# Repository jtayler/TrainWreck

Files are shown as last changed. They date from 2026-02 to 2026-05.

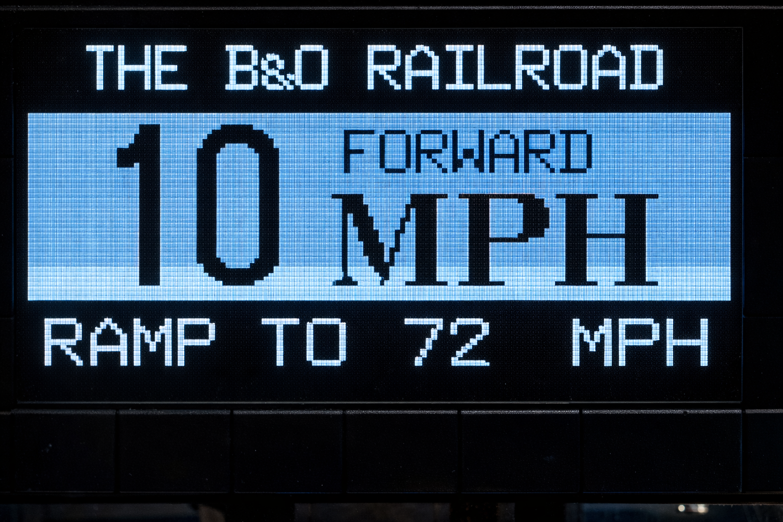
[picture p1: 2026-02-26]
controltower.com/images/display.png

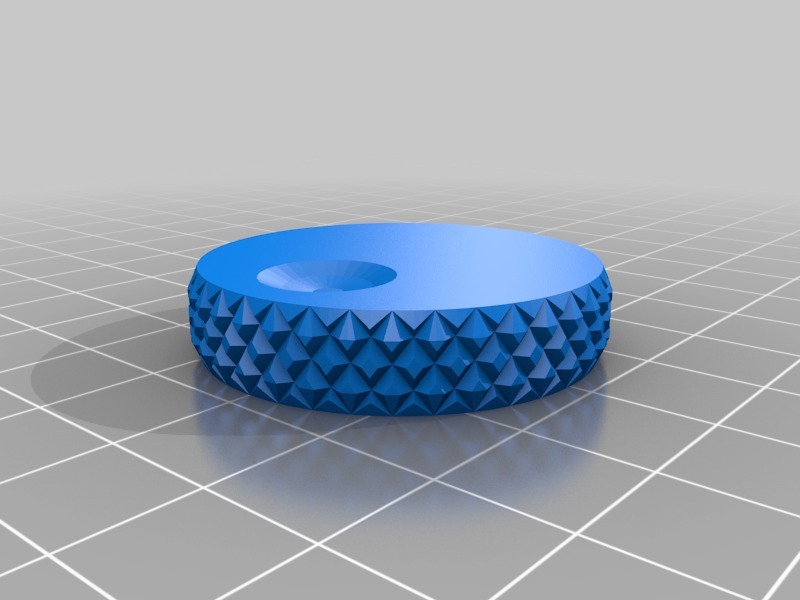
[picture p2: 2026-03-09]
case/Knob/knurled_LCD-knob-2-dent.jpg

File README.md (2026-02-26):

# RailStation — Control Tower  
### Powered by RailOS™

> **A luxury smart power controller for any model train.**  
> RailStation replaces a “dumb” power supply with our special **control tower**. A smart control tower is a power controller with an integrated full-size traffic light; smooth motion, a large digital display, automatic station docking, and synchronized signal and lighting choreography.
> **Easy to enjoy.** Grab the knob anytime for manual override—let go and it glides back into automation. The large display changes with a click to show the list of Routes and you can scroll and pipck another Route, or click and hold a long-press to adjust settings and save them.

---

## What it does (in one minute)

- **Auto-calibrates to your layout** so station finding literally “just works.”
- Runs **scripted routes** with realistic pacing, raping speed and a human feel.
- Drives a **real traffic light** (top-and-center) + **station lights** with choreography.
- Supports **Z to G scale** by respecting a configurable power ceiling.
- The built-in series of fun Lines will run for **2–3 hours continuously** and will repeat in an endless loop.

---

## Signature features

### Smooth motion you can feel
RailOS uses non-linear ramping so starts/stops feel intentional—no lurch, no toy throttle vibe.

### Large, luxurious display
A large, elegant display turns your train into the centerpiece — with a beautifully simple interface that makes control effortless.

### Station docking that actually lands
A TINY IR sensor is used for automatic station arrival behavior: approach → crawl → stop → dwell → depart.

### Real signals, not decoration
**Traffic Light**
- **🔴 Red**: Halted / at-station
- **🟡 Yellow**: Decelerating / slow leg
- **🟢 Green**: Accelerating / fast leg

### Station lights with choreography
Four “posts” are programmable as a group:
- arrival blink patterns
- alternating pairs
- departure urgency
- slow fade-out to dark

Plus one extra output for “anything”: gate motor, windmill, sign, beacon, etc.

### Manual override that feels natural
Turn the knob → you’re in control instantly.  
Release it → after a brief pause, RailOS blends you back into the active route smoothly.

---

## Route Library (examples)
A RailStation isn’t just speed—it’s **story**. Each route has a personality:
- Pennsylvania Line
- California Zephyr
- The Orient Express
- Reading Railroad
- Flying Scotsman
- Hudson River Ltd
- 20th Century Ltd
- Taking Pelham 123  
…and more.

Routes are **editable, reorderable, deletable** and your changes **stick**.

---

## The “Human Element” controls (simple, but deep)

RailOS keeps it easy: you pick a line, and a few “human” traits shape the feel.

### Schedule (when are we running?)
- **HIGH_FREQ** — subway-like: short waits, quick turnarounds, more movement  
- **PEAK** — purposeful: brisk legs, tighter dwell times, fewer “lingers”  
- **OFF_PEAK** — relaxed: longer dwells, calmer pacing, more breathing room  

### Equipment (what kind of train is this?)
- **BULLET** — confident acceleration, longer fast legs, shorter crawls  
- **SHUTTLE** — frequent stops, shorter legs, snappy station work  
- **FREIGHT** — heavier feel: longer ramps, longer slow legs, deliberate departures  

### Service (how predictable is it?)
- **NONSTOP** — fewer station events, more continuous running  
- **LIMITED** — selective stops, “express” pacing and timing  
- **UNPREDICTABLE** — controlled variation: small changes that feel human, not random  

### Range (what kind of run is this?)
- **LOCAL** — close stations, frequent choreography, short dwell cycles  
- **SHORT_RUN** — medium legs, balanced station time  
- **LONG_HAUL** — longer cruising legs, fewer but more “cinematic” station moments  

These traits automatically influence:
- station dwell time
- leg length and speed targets
- ramp aggressiveness
- lighting choreography timing
- controlled variation (the “human element”)

---

## Scales & power
RailStation works across scales by capping output with **MAX_SPEED**:
- tiny trains (T/Z) behave safely
- large trains (O/G) still feel powerful
- same controller, different ceiling

---

## RailOS 1.0
RailOS is the C++ firmware that runs RailStation Control Tower:
- motion physics + ramp engine
- station sensor logic
- profile persistence (edits stick)
- signal + station light choreography
- continuous route runner
- manual override blending

---

## Our Motto
**Easy to enjoy.**  
**Your train. Our brain.**

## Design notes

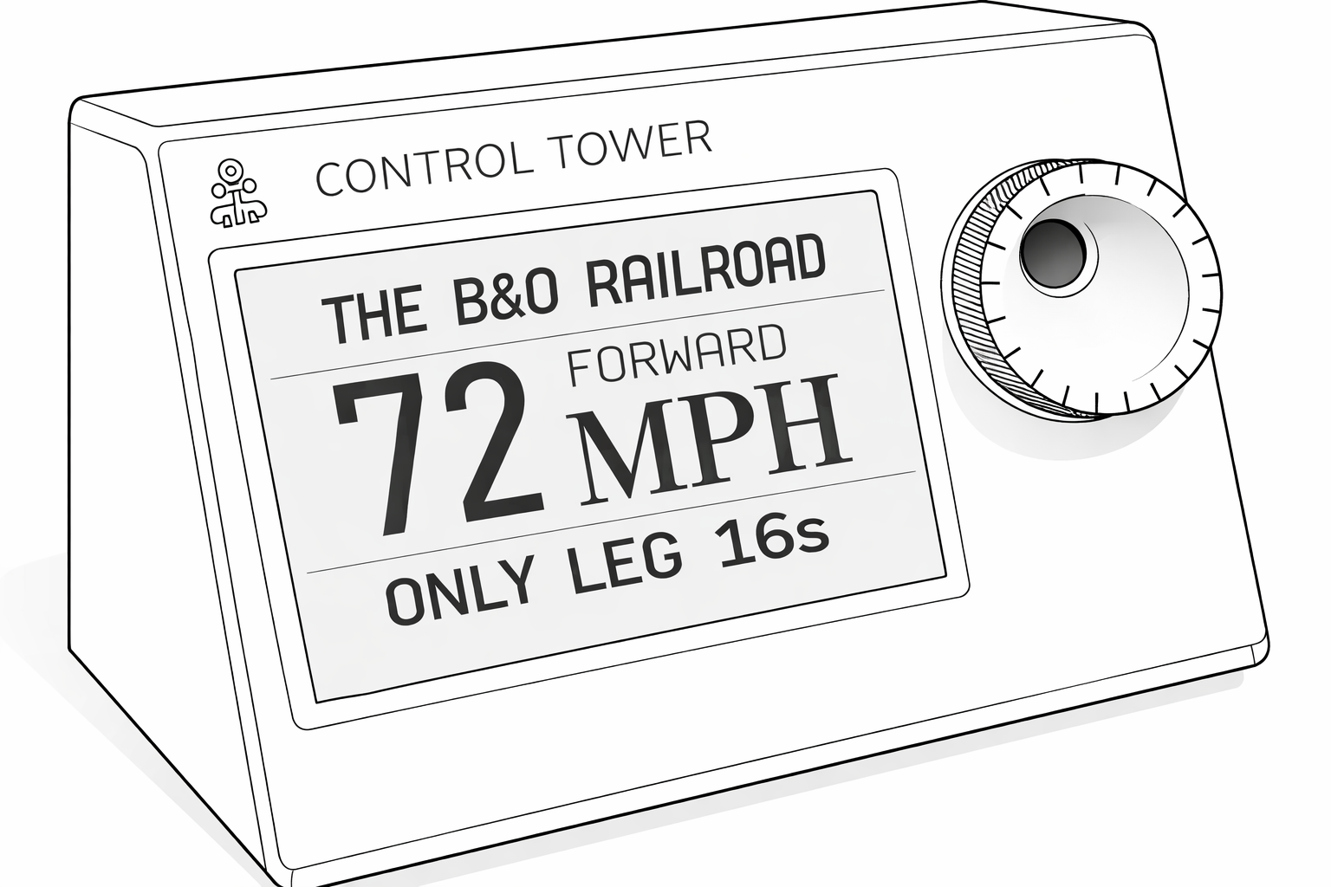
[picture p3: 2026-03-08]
controltower.com/images/lineart.png

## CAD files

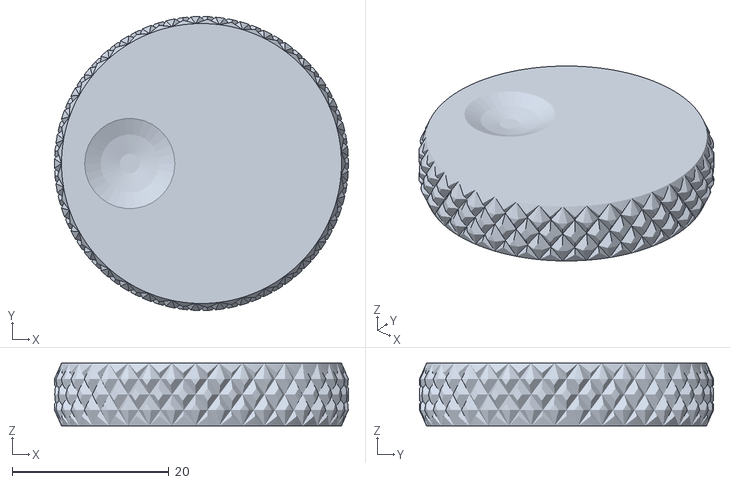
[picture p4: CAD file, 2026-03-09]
case/Knob/knurled_LCD-knob-2-dent.stl
37.5 x 37.5 x 8.00

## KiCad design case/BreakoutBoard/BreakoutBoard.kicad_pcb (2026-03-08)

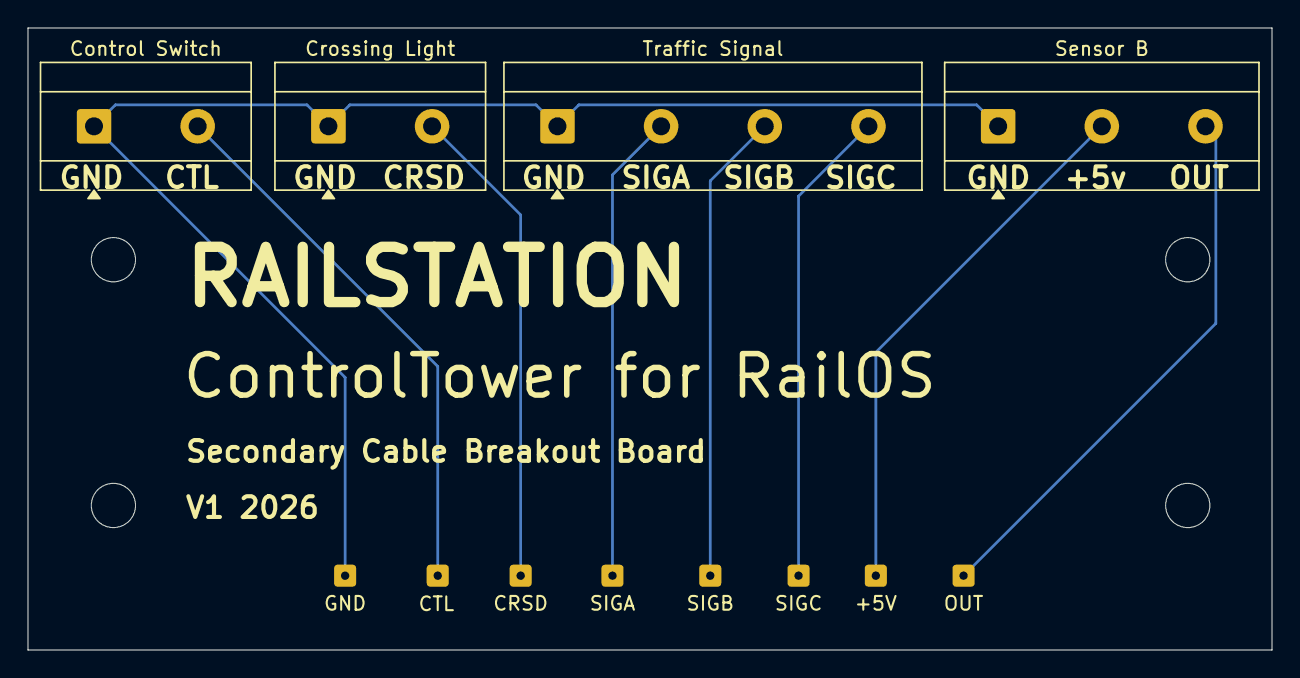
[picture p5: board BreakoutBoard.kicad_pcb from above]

Board: 2 copper layers, 90.0 x 45.0 mm, 15 parts (0 on the bottom side), 7 nets.

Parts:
+5V: GND; SolderWire-0.1sqmm_1x01_D0.4mm_OD1mm
B.R.: MountingHole_3.2mm_M3
BottomLeft: MountingHole_3.2mm_M3
CRSD: GND; SolderWire-0.1sqmm_1x01_D0.4mm_OD1mm
Control Switch: Crossing Light; TerminalBlock_MetzConnect_Type171_RT13702HBWC_1x02_P7.50mm_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
Crossing Light: Crossing Light; TerminalBlock_MetzConnect_Type171_RT13702HBWC_1x02_P7.50mm_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
GND: GND; SolderWire-0.1sqmm_1x01_D0.4mm_OD1mm
OUT: GND; SolderWire-0.1sqmm_1x01_D0.4mm_OD1mm
SIGA: GND; SolderWire-0.1sqmm_1x01_D0.4mm_OD1mm
SIGB: GND; SolderWire-0.1sqmm_1x01_D0.4mm_OD1mm
SIGC: GND; SolderWire-0.1sqmm_1x01_D0.4mm_OD1mm
Sensor B: Sensor; TerminalBlock_MetzConnect_Type171_RT13703HBWC_1x03_P7.50mm_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
TopLeft: MountingHole_3.2mm_M3
TopRight: MountingHole_3.2mm_M3
Traffic Signal: TerminalBlock_MetzConnect_Type171_RT13704HBWC_1x0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; TerminalBlock_MetzConnect_Type171_RT13704HBWC_1x04_P7.50mm_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

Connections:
A2: SIGA.1, Traffic Signal.2
B2: SIGB.1, Traffic Signal.3
C2: SIGC.1, Traffic Signal.4
D2: CRSD.1, Crossing Light.2
GND2: Control Switch.1, Crossing Light.1, GND.1, Sensor B.1, Traffic Signal.1
OUT2: OUT.1, Sensor B.3
VCC2: +5V.1, Sensor B.2

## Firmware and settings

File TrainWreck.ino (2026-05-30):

#include <SPI.h>
#include <EEPROM.h>
#include <U8g2lib.h>
#include <avr/pgmspace.h>
#include <Encoder.h>

// --- pins ---
#define CS_PIN 10
#define DC_PIN 9
#define RST_PIN 8

// --- persistence store ---
#define EEPROM_VERSION 15

struct Persist {
  byte version;
  unsigned long lapFwd;
  unsigned long lapRev;
  unsigned long trainMs;
  uint8_t lastRouteIndex;
};

// --- display driver ---
U8G2_SH1106_128X64_NONAME_1_4W_HW_SPI u8g2(U8G2_R0, 10, 9, 8);

// -------- pins --------
const int IR_PIN = A0;
const int in1Pin = 5;
const int in2Pin = 6;
const int CLK_PIN = 2;  // INT0
const int DT_PIN = 3;   // INT1
const int buttonPin = 12;
const int RED_PIN = 7;
const int YEL_PIN = A5;
const int GRN_PIN = 4;

const int STN1_PIN = A1;
const int STN2_PIN = A2;
const int STN3_PIN = A3;
const int STN4_PIN = A4;

// --- startup & station ---
long stationDist = 1 * 60;
bool calibrateAtStartup = true;
bool testStationMode = false;

// -------- tuning ---------
const int MAX_SPEED = 255;
const int DOCKING_SPEED = 165;
const int RAMP_STEP = 10;
const int RAMP_MINUTES = 120;
const float MAX_MPH = 72;

// ------- calibration ---------
unsigned long snoozingMinutes = 20;
bool sensorEnabled = false;
volatile bool calibrating = false;
bool hasCalibrated = false;
bool stationArmed = false;
unsigned long stationTick = 0;
long lastPos = 0;

// ----- dip behavior -----
const unsigned long DIP_TIME = 9600;

// -------- calibrate --------
unsigned long storedLapFwd = 0;
unsigned long storedLapRev = 0;
unsigned long irDipDurationMs = 0;

// -------- display --------
bool isMPH = true;
bool lastDirection = true;
int globalCurrentSpeed = 0;
volatile bool abortRoute = false;
volatile bool restartRequested = false;
uint8_t currentRouteIndex = 0;

char line1[64] = "STATUS";
char line2[64] = "0";
char line3[64] = "READY";

enum StationState {
  CRUISING,
  ARRIVING,
  AT_STATION,
  DEPARTING,
  COOL_DOWN
};

StationState currentStationState = CRUISING;
unsigned long stateStartTime = 0;
bool manualLocked = false;
bool trippedDirection = false;

int currentSpeedNumber(int pwm) {
  if (isMPH) {
    return speedToMph(pwm);
  }
  return speedToKph(pwm);
}

char* perHourName() {
  if (isMPH) {
    return "MPH";
  }
  return "KPH";
}

int speedToMph(int pwm) {
  int max = maxSpeed();

  if (pwm < 0) pwm = 0;
  if (pwm > max) pwm = max;

  return ((long)pwm * MAX_MPH) / max;
}

int speedToKph(int pwm) {
  pwm = constrain(pwm, 0, maxSpeed());
  return (pwm * MAX_MPH * 161) / (maxSpeed() * 100);
}

Encoder speedKnob(CLK_PIN, DT_PIN);

volatile int targetSpeed = 0;
volatile bool targetDirty = false;
enum ControlMode { AUTO,
                   MANUAL };
ControlMode mode = AUTO;
unsigned long lastManualInput = 0;

void readEncoderStep() {
  long pos = speedKnob.read() / 4;

  // --- KNOB ENTERS MANUAL IF AUTO ---
  if (pos != lastPos) {
    lastManualInput = millis();

    if (mode == AUTO) {
      mode = MANUAL;
      restartRequested = true;
      abortRoute = true;
      stationArmed = false;
    }

    lastPos = pos;
  }

  // --- BUTTON TOGGLES LOCK ---
  static unsigned long lastPress = 0;

  if (digitalRead(buttonPin) == LOW) {
    if (millis() - lastPress > 250) {
      lastPress = millis();

      // If in manual, toggle lock state
      if (mode == MANUAL) {
        if (manualLocked) {
          manualLocked = false;
        } else {
          manualLocked = true;
        }
      }
    }
  }
}
static long delta = 0;

void manualControlLoop() {
  snprintf(line3, sizeof(line3), "MANUAL CONTROL");
  draw();

  static unsigned long snoozeTime = 0;
  snoozeTime = millis();  // seed on entry — prevent false snooze trigger
  delta = 0;              // clear stale direction from prior session

  while (true) {
    updateStationLights();
    long pos = speedKnob.read() / 4;

    if (currentStationState == CRUISING) {
      if (globalCurrentSpeed == 0) {
        setStationState(AT_STATION);
      } else if (delta < 0 && globalCurrentSpeed < DOCKING_SPEED) {
        setStationState(ARRIVING);
      }
    } else if (currentStationState == AT_STATION) {
      if (delta > 0 && globalCurrentSpeed > 0) {
        setStationState(DEPARTING);
      }
    }

    if (globalCurrentSpeed == 0) {
      if (millis() - snoozeTime < (snoozingMinutes * 60 * 1000)) {
        if (delta < 0) {
          if (globalCurrentSpeed == 0) {
            signalRed();
          } else {
            signalYellow();
          }
        } else if (delta > 0) {
          signalGreen();
        } else {
          signalRed();
        }
      } else {
        signalOff();
        setStationState(CRUISING);
        stationLightsOff();
      }
    }
    if (pos != lastPos) {
      long oldPos = lastPos;
      lastPos = pos;
      int prevSpeed = globalCurrentSpeed;
      delta = oldPos - pos;

      globalCurrentSpeed += delta * 6;
      if (delta < 0 && globalCurrentSpeed < 10) globalCurrentSpeed = 0;

      globalCurrentSpeed = constrain(globalCurrentSpeed, 0, 255);

      if (globalCurrentSpeed == 0 && prevSpeed > 0) {
        lastDirection = !lastDirection;
        snoozeTime = millis();
      }

      if (globalCurrentSpeed > 0) {
        snoozeTime = millis();
      }

      if (globalCurrentSpeed == 0) signalRed();
      else if (delta < 0) signalYellow();
      else signalGreen();

      writeMotor(lastDirection, globalCurrentSpeed);
      snprintf(line2, sizeof(line2), "%d %s", speedToMph(globalCurrentSpeed), perHourName());
      draw();
    }

    static unsigned long lastPress = 0;
    if (digitalRead(buttonPin) == LOW) {
      if (millis() - lastPress > 250) {
        lastPress = millis();
        snprintf(line3, sizeof(line3), "EXIT MANUAL");
        draw();
        break;
      }
    }
  }
  mode = AUTO;
  restartRequested = true;
  abortRoute = false;
  stationArmed = false;
}

// -------- dip --------

int maxSpeed() {
  return constrain(MAX_SPEED, 128, 255);
}

int dipSpeed() {
  return max(50, (maxSpeed() * 32) / 100);
}

int dipSpeedFast() {
  return max(dipSpeed() + 10, (maxSpeed() * 46) / 100);
}

// -------- go! --------
bool currentDirection = true;

void go(bool forward, int speed, unsigned long runTime, int dipCount) {
  if (abortRoute) return;

  unsigned long pauseTime = random(6, 20);
  setDirection(forward);
  rampSpeed(speed);

  if (dipCount > 0) {
    long jitterPct = random(-20, 21);  // -20% to +20%
    unsigned long segment = (runTime * 1000UL * (100 + jitterPct)) / 100;
    for (int i = 0; i < dipCount; i++) {
      if (abortRoute) return;
      unsigned long legStartTime = millis();
      while (millis() - legStartTime < segment) {
        if (abortRoute) return;
        snprintf(line3, sizeof(line3), "%s %ds", "FAST LEG", segment / 1000);
        draw();
        updateStationLights();
        readEncoderStep();
      }
      rampSpeed(random(dipSpeed(), dipSpeedFast()));
      long dipJitterPct = random(-20, 21);  // -20% to +20%
      unsigned long thisDipTime = (DIP_TIME * (100 + dipJitterPct)) / 100;
      unsigned long dipStartTime = millis();
      while (millis() - dipStartTime < thisDipTime) {
        if (abortRoute) return;
        snprintf(line3, sizeof(line3), "%s %ds", "SLOW LEG", DIP_TIME / 1000);
        draw();
        updateStationLights();
        readEncoderStep();
      }
      rampSpeed(random(speed * 0.85, speed));
    }
    unsigned long segmentStartTime = millis();
    while (millis() - segmentStartTime < segment) {
      if (abortRoute) return;
      snprintf(line3, sizeof(line3), "%s %ds", "FAST LEG", segment / 1000);
      draw();
      updateStationLights();
      readEncoderStep();
    }
  } else {
    unsigned long onlyStartTime = millis();
    while (millis() - onlyStartTime < runTime * 1000) {
      if (abortRoute) return;
      snprintf(line3, sizeof(line3), "%s %ds", "ONLY LEG", runTime);
      draw();
      updateStationLights();
      readEncoderStep();
    }
  }
  readEncoderStep();

  rampSpeed(0);
  stateStartTime = millis();
  unsigned long pauseMs = max(0L, (long)(pauseTime * 1000UL));
  while (millis() - stateStartTime < pauseMs) {
    if (abortRoute) return;
    snprintf(line3, sizeof(line3), "%s %ds", "AT STATION", pauseTime);
    draw();
    updateStationLights();
    readEncoderStep();
  }
  setStationState(DEPARTING);
  updateStationLights();
  unsigned long start = millis();
  while (millis() - start < 4000) {
    if (abortRoute) return;
    updateStationLights();
    snprintf(line3, sizeof(line3), "%s", "NOW DEPARTING");
    draw();
    readEncoderStep();
  }
}

// -------- signal --------
void signalOff() {
  digitalWrite(YEL_PIN, LOW);
  digitalWrite(GRN_PIN, LOW);
  digitalWrite(RED_PIN, LOW);
}

void signalRed() {
  digitalWrite(YEL_PIN, LOW);
  digitalWrite(GRN_PIN, LOW);
  digitalWrite(RED_PIN, HIGH);
}

void signalYellow() {
  digitalWrite(RED_PIN, LOW);
  digitalWrite(GRN_PIN, LOW);
  digitalWrite(YEL_PIN, HIGH);
}

void signalGreen() {
  digitalWrite(RED_PIN, LOW);
  digitalWrite(YEL_PIN, LOW);
  digitalWrite(GRN_PIN, HIGH);
}

void updateTafficSignal(int speed, bool rampUp) {
  if (calibrating) return;
  if (speed == 0) {
    signalRed();
    return;
  }
  if (rampUp) {
    signalGreen();
  } else {
    signalYellow();
  }
}

// -------- lights --------

const unsigned long ARRIVE_BLINK_MS = 4000;
const unsigned long DEPART_BLINK_MS = 12000;
const unsigned long HOLD_AFTER_LEAVE = 8000;
const unsigned long FADE_MS = 6000;

void stationLightsOff() {
  digitalWrite(STN1_PIN, LOW);
  digitalWrite(STN2_PIN, LOW);
  digitalWrite(STN3_PIN, LOW);
  digitalWrite(STN4_PIN, LOW);
}

void stationLightsOn() {
  digitalWrite(STN1_PIN, HIGH);
  digitalWrite(STN2_PIN, HIGH);
  digitalWrite(STN3_PIN, HIGH);
  digitalWrite(STN4_PIN, HIGH);
}

void fadeToBlackMs(unsigned long ms) {
  static unsigned long start = 0;
  static int phase = 0;

  if (phase == 0) {
    start = millis();
    phase = 1;
  }

  unsigned long step = ms / 4;
  unsigned long elapsed = millis() - start;

  if (phase == 1 && elapsed >= step) {
    digitalWrite(STN1_PIN, LOW);
    phase = 2;
  }
  if (phase == 2 && elapsed >= step * 2) {
    digitalWrite(STN2_PIN, LOW);
    phase = 3;
  }
  if (phase == 3 && elapsed >= step * 3) {
    digitalWrite(STN3_PIN, LOW);
    phase = 4;
  }
  if (phase == 4 && elapsed >= step * 6) {
    digitalWrite(STN4_PIN, LOW);
    phase = 0;  // finished
  }
}

void alternateBlink(unsigned long now) {
  static unsigned long lastToggle = 0;
  static bool phase = false;

  if (now - lastToggle >= 250) {
    lastToggle = now;
    phase = !phase;
    //Serial.print("BLINKING! ");

    if (phase) {
      digitalWrite(STN1_PIN, LOW);
      digitalWrite(STN2_PIN, HIGH);
      digitalWrite(STN3_PIN, HIGH);
      digitalWrite(STN4_PIN, HIGH);
    } else {
      digitalWrite(STN1_PIN, HIGH);
      digitalWrite(STN2_PIN, HIGH);
      digitalWrite(STN3_PIN, HIGH);
      digitalWrite(STN4_PIN, LOW);
    }
  }
}

void setStationState(StationState s) {
  if (currentStationState == s) return;
  currentStationState = s;
  stateStartTime = millis();
}

void updateStationLights() {
  if (calibrating) return;
  unsigned long elapsed = millis() - stateStartTime;

  switch (currentStationState) {
    case ARRIVING:
      alternateBlink(millis());
      if (elapsed >= ARRIVE_BLINK_MS)
        setStationState(AT_STATION);
      break;

    case DEPARTING:
      alternateBlink(millis());
      if (elapsed >= DEPART_BLINK_MS)
        setStationState(COOL_DOWN);
      break;

    case COOL_DOWN:
      static bool fading = false;

      if (!fading) {
        stationLightsOn();
        if (elapsed >= HOLD_AFTER_LEAVE) {
          fading = true;
          stateStartTime = millis();
        }
      } else {
        fadeToBlackMs(FADE_MS);
        if (millis() - stateStartTime >= FADE_MS) {
          fading = false;
          setStationState(CRUISING);
        }
      }
      break;
    case AT_STATION:
      stationLightsOn();  // Solid lights while stopped
      break;

    case CRUISING:
      // All station pins LOW
      digitalWrite(STN1_PIN, LOW);
      digitalWrite(STN2_PIN, LOW);
      digitalWrite(STN3_PIN, LOW);
      digitalWrite(STN4_PIN, LOW);
      break;
  }
}

// -------- motor --------
void writeMotor(bool forward, int pwm) {
  pwm = constrain(pwm, 0, maxSpeed());
  globalCurrentSpeed = pwm;
  currentDirection = forward;

  if (forward) {
    digitalWrite(in2Pin, LOW);  // This stays Digital (The Ground)
    analogWrite(in1Pin, pwm);   // This uses PWM (The Speed)
  } else {
    digitalWrite(in1Pin, LOW);  // This stays Digital (The Ground)
    analogWrite(in2Pin, pwm);   // This uses PWM (The Speed)
  }
}

// -------- direction --------
void setDirection(bool forward) {
  lastDirection = forward;
}

// -------- IR sensor --------
bool trainPassingIR(bool reset = false) {
  static int baseline = -1;
  static bool armed = false;
  static bool inDip = false;
  static unsigned long armStartMs = 0;
  static unsigned long dipStartMs = 0;
  static unsigned long lastBaselineUpdate = 0;

  int v = analogRead(IR_PIN);
  unsigned long now = millis();

  if (reset || baseline < 1) {
    baseline = v;
    armed = false;
    inDip = false;
    armStartMs = now;
    lastBaselineUpdate = now;
    return false;
  }

  if (!armed) {
    int p = ((long)(baseline - v) * 100L) / baseline;
    if (p < 8) baseline = (baseline * 7 + v) / 8;
    if (now - armStartMs >= 750) armed = true;
    return false;
  }

  int percent = ((long)(baseline - v) * 100L) / baseline;

  if (!inDip) {
    if (percent >= 12) {
      inDip = true;
      dipStartMs = now;
    } else if (percent < 4 && now - lastBaselineUpdate >= 500) {
      baseline = (baseline * 15 + v) / 16;
      lastBaselineUpdate = now;
    }
  } else {
    if (percent <= 5) {
      irDipDurationMs = now - dipStartMs;
      inDip = false;
      return true;
    }
  }

  return false;
}

// -------- ramp --------
void rampSpeed(int target) {
  static int current = 0;
  if (current != globalCurrentSpeed) current = globalCurrentSpeed;

  static bool lastSensorState = false;
  static bool dockedThisStop = false;
  int start = current;
  int delta = abs(target - start);
  bool rampUp = target > current;
  trippedDirection = (globalCurrentSpeed > 0);

  if (target == 0) stationArmed = false;

  if (target != 0) dockedThisStop = false;

  if (target == current) {
    globalCurrentSpeed = current;
    return;
  }

  updateTafficSignal((rampUp ? 1 : current), rampUp);

  unsigned long rampBlockStart = 0;

  while (current != target) {
    if (abortRoute) return;
    if (target == 0 && current < (DOCKING_SPEED - 10)) {
      setStationState(ARRIVING);
    }
    if (sensorEnabled && target == 0 && !dockedThisStop) {
      if (current <= DOCKING_SPEED) {
        snprintf(line3, sizeof(line3), "%s", "BRAKE TO HALT");
        draw();
        trainPassingIR(true);
        while (!stationArmed) {
          if (abortRoute) return;
          if (trainPassingIR()) {
            stationArmed = true;
            stationTick = millis();
          }
          updateStationLights();
          readEncoderStep();
        }

        unsigned long waitMs = calculateStationPause(lastDirection);
        unsigned long startWait = millis();
        while (millis() - startWait < waitMs) {
          if (abortRoute) return;
          updateStationLights();
          draw();
          readEncoderStep();
        }
        setStationState(AT_STATION);
        dockedThisStop = true;
        rampBlockStart = millis();
        start = current;
        delta = current;
      }
    }
    // ---- S-CURVE RAMP ----
    int progressed = abs(current - start);
    float phase = (delta == 0) ? 1.0 : (float)progressed / delta;
    int step = max(1, (int)(RAMP_STEP * (0.5 + 1.5 * phase * (1 - phase))));
    if (rampUp) {
      current += step;
      if (current > target) current = target;
    } else {
      current -= step;
      if (current < target) current = target;
    }
    // ---- OUTPUT ----
    globalCurrentSpeed = current;
    if (target == 0) {
      updateTafficSignal(current, rampUp);
    } else {
      // snprintf(line3, sizeof(line3), "BOO!");

      int mph = speedToMph(target);
      
      const char* unit = perHourName();
      char* ramp = rampUp ? "RAMP TO" : "DOWN TO";

      snprintf(line3, sizeof(line3), "%s %d %s",
               ramp,
               mph,
               unit);
    }
    if (targetDirty) {
      targetDirty = false;
      target = targetSpeed;
      start = current;
      delta = abs(target - start);
      rampUp = target > current;
    }
    writeMotor(lastDirection, current);
    snprintf(line2, sizeof(line2), "%d %s", speedToMph(current), perHourName());
    // Serial.println(line3);
    draw();
    updateStationLights();
    readEncoderStep();
  }
  updateTafficSignal(current, rampUp);

  if (target == 0 && rampBlockStart > 0) {
    unsigned long lapMs = lastDirection ? storedLapFwd : storedLapRev;
    unsigned long rampBlockMs = (unsigned long)RAMP_MINUTES * lapMs / 720L;
    while (millis() - rampBlockStart < rampBlockMs) {
      if (abortRoute) return;
      updateStationLights();
      readEncoderStep();
    }
  }
}

void calibrateTrain() {
  calibrating = true;
  signalOff();
  stationLightsOff();
  snprintf(line1, sizeof(line1), "CALIBRATE ENGINE");
  draw();
  storedLapFwd = measureLap(true);
  if (abortRoute) {
    calibrating = false;
    return;
  }
  storedLapRev = measureLap(false);
  if (abortRoute) {
    calibrating = false;
    return;
  }

  Persist p;
  p.version = EEPROM_VERSION;
  p.lapFwd = storedLapFwd;
  p.lapRev = storedLapRev;
  p.trainMs = irDipDurationMs;
  p.lastRouteIndex = currentRouteIndex;
  EEPROM.put(0, p);

  // Serial.print("FWD lap ms: "); Serial.println(storedLapFwd);
  // Serial.print("REV lap ms: "); Serial.println(storedLapRev);
  if (storedLapFwd > 0) {
    // Serial.print("Train size: "); Serial.print(irDipDurationMs * 720UL / storedLapFwd); Serial.println(" cmin");
  }
  // Serial.print("FWD coast ms: "); Serial.println(calculateStationPause(true));
  // Serial.print("REV coast ms: "); Serial.println(calculateStationPause(false));
  calculateStationPause(true);
  calculateStationPause(false);
  setStationState(DEPARTING);
  calibrating = false;
}

void loadFromEEPROM() {
  Persist p;
  EEPROM.get(0, p);
  if (p.version == EEPROM_VERSION) {
    storedLapFwd = p.lapFwd;
    storedLapRev = p.lapRev;
    irDipDurationMs = p.trainMs;
    currentRouteIndex = p.lastRouteIndex;
  }
}

unsigned long calculateStationPause(bool forward) {
  long correction = (long)(irDipDurationMs / 2);
  if (forward) {
    if (storedLapFwd == 0) return 0;
    long ms = (long)((unsigned long)stationDist * storedLapFwd / 720UL) - correction;
    // Serial.print("FWD coast="); Serial.println(max(0L, ms));
    return (unsigned long)max(0L, ms);
  } else {
    if (storedLapRev == 0) return 0;
    long ms = (long)((480L - stationDist) * storedLapRev / 720L) - correction;
    // Serial.print("REV coast="); Serial.println(max(0L, ms));
    return (unsigned long)max(0L, ms);
  }
}
// Function to measure lap time
unsigned long measureLap(bool forward) {
  unsigned long start = 0;
  draw();

  setDirection(forward);
  for (int s = 0; s <= DOCKING_SPEED; s += 6) {
    if (abortRoute) {
      writeMotor(forward, 0);
      return 0;
    }
    globalCurrentSpeed = s;
    snprintf(line2, sizeof(line2), "%d %s", speedToMph(globalCurrentSpeed), perHourName());
    draw();
    readEncoderStep();
    writeMotor(forward, s);
  }

  trainPassingIR(true);
  while (!trainPassingIR()) {
    if (abortRoute) return 0;
    readEncoderStep();
  }
  snprintf(line3, sizeof(line3), "MARK");
  draw();

  delay(300);

  start = millis();
  trainPassingIR(true);
  while (!trainPassingIR()) {
    if (abortRoute) return 0;
    readEncoderStep();
  }

  snprintf(line3, sizeof(line3), "SET");
  draw();

  unsigned long lap = millis() - start;

  bool wasSensor = sensorEnabled;
  sensorEnabled = false;
  rampSpeed(0);
  sensorEnabled = wasSensor;
  snprintf(line3, sizeof(line3), "GO!");
  draw();

  return lap;
}


// -------- route strings (PROGMEM) --------
const char rt_pelham[] PROGMEM = "Taking Pelham 123";
const char rt_hogwarts[] PROGMEM = "Hogwarts Express";
const char rt_zephyr[] PROGMEM = "California Zephyr";
const char rt_polar[] PROGMEM = "The Polar Express";
const char rt_orient[] PROGMEM = "The Orient Express";
const char rt_broadway[] PROGMEM = "Broadway Limited";
const char rt_silver[] PROGMEM = "The Silver Streak";
const char rt_scotsman[] PROGMEM = "Flying Scotsman";
const char rt_cannon[] PROGMEM = "Cannonball Express";
const char rt_circle[] PROGMEM = "The Circle Line";
const char rt_empire[] PROGMEM = "Empire State Exp";
const char rt_ghan[] PROGMEM = "The Great Ghan";
const char rt_century[] PROGMEM = "20th Century Ltd";
const char rt_thomas[] PROGMEM = "Thomas & Friends";
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
void loop() {

  if (abortRoute) {
    abortRoute = false;
    manualControlLoop();
    return;
  }

  if (restartRequested) {
    restartRequested = false;
    rampSpeed(maxSpeed());
    runRoute(currentRouteIndex);
    return;
  }

  if (!hasCalibrated && calibrateAtStartup && sensorEnabled) {
    calibrateTrain();
    hasCalibrated = true;
    return;
  }

  if (testStationMode) {
    testStationLoop();
    return;
  }

  runRoutes();
}

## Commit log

2026-01-23 clean up after wrong file situation!
    [TrainWreck.ino]
2026-01-24 second pass, seems to pass test. a bit different voltage cliff seems less accurate on the spectrum, so the max speed is greatly reduced and the ramps needed adjustment to suit.
2026-01-24 more adjustments to get the reporting correctly timed for all events.
    [TrainWreck.ino]
2026-02-07 fix up reporting, prep for traffic light and update details for working train! hooray!
    [TrainWreck.ino]
2026-02-08 traffic light installed and wired. just waiting for the item itself...
2026-02-12 prepare for IR and try to see why this traffic light will NOT WORK!!
    [TrainWreck.ino]
2026-02-14 updating speed and ramp rates to reach 10v vs 6 or less even this may improve reliability
2026-02-15 fully operational ramp and traffic light support, first pass at timer tick to land at a station but this is going well for a change-- no jinx
2026-02-20 motor controller hell
2026-02-22 ok! Sensor working! Train seems to reliably end at the station, no way - just no fucking way - this is so cool
2026-02-24 store basics to memory, perform a startup configuration. very cool whatever the train acts like forward and reverse are measured so it is accurate...
    [TrainWreck.ino]
2026-02-25 uncertain if it's best to go directly into the next phase if we're uncertain where along the ring the trigger happens. what I likely want to do is start the blink at a pwm level or I might be already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
2026-02-26 Revise README description for RailStation
    Updated the description of RailStation for clarity and detail.
2026-02-26 fixings make it run smooth
    [TrainWreck.ino]
2026-03-01 detail work around the calibration, prepare for manual control.
2026-03-02 try to get an encoder firing from hardware interrupt
2026-03-02 the wheel and button are starting to work!!! far out!
2026-03-04 splash screen, startup fixes and working calibration are all there now.
    [TrainWreck.ino]
2026-03-04 draw some line art of the upcomging display and website along with finally smoothing out the darn thing's reverse when stopped. traffic lights work in manual etc.
    [TrainWreck.ino]
2026-03-06 start building up the assets
    [BreakoutBoard.kicad_pcb, BreakoutBoard.kicad_sch]
2026-03-07 add a breakout board and connector stuff
    [BreakoutBoard.kicad_pcb]
2026-03-07 rest of it
    [BreakoutBoard.kicad_pcb]
2026-03-07 updates moving toward start of manufacture
    [BreakoutBoard.kicad_pcb]
2026-03-08 let's update!
    [BreakoutBoard.kicad_pcb, BreakoutBoardSecondary.kicad_pcb]
2026-03-09 add the knob
    [BreakoutBoardSecondary.kicad_pcb, knurled_LCD-knob-2-dent.stl]
2026-03-30 this code is too big for the poor nano! 2.0 must be moved up in schedule.
    [TrainWreck.ino]
2026-04-28 clean up text fix up ramping and a bunch of stuff
    [TrainWreck.ino]
2026-04-28 move toward that 2.0 rail os ramp and calibration. back to dual calibrate and EPROM handling.
2026-04-28 we have to account for changes to the calibration and enforce recalibration when needed.
2026-04-30 fix it up a tad -- see about this ramp issue --
    [TrainWreck.ino]
2026-05-06 reliable hourly landing -finally
